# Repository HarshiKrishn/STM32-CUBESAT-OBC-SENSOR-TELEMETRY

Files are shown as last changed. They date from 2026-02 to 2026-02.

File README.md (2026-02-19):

# STM32 CubeSat OBC – Sensor Telemetry System

A custom-designed STM32-based On-Board Computer (OBC) for CubeSat applications with integrated sensor telemetry and power subsystem.

---

## 🚀 Overview

This project implements a CubeSat OBC built around STM32 microcontroller for:

- Sensor data acquisition
- Telemetry formatting
- Power subsystem integration
- Communication interface support

Designed completely in KiCad.

---

## 🧠 System Architecture

- MCU: STM32
- Power Regulation: 3.3V & 5V rails
- Communication:
  - UART
  - I2C
  - SPI
- Telemetry Output Support

---

## 🔌 Power Subsystem

- Battery input stage
- Voltage regulation
- Protection circuitry
- Filtering and decoupling

---

## 📡 Telemetry

- Sensor data acquisition
- Structured data formatting
- Ready for ground-station transmission

---

## 🖥️ Tools Used

- KiCad (Schematic + PCB)
- MATLAB (Validation)
- Proteus (Simulation)
- OnShape (Mechanical validation)

---

---

## 📂 Repository Structure

- `/Schematic`
- `/PCB`
- `/3D_Images`
- `/Docs`

---
## 3D PCB View

### Top View
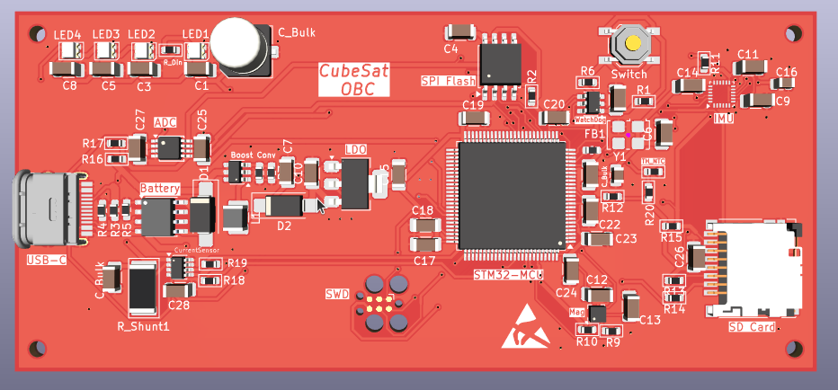
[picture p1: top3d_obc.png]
Top View


### Bottom View
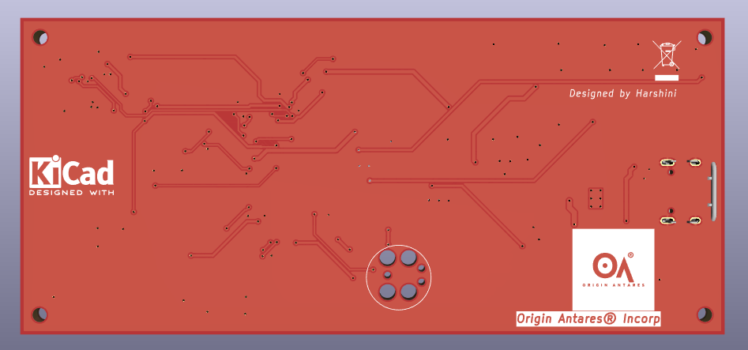
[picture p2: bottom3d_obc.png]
Bottom


## 👤 Author

Designed and developed by Harshini  
Embedded Systems & PCB Design Enthusiast

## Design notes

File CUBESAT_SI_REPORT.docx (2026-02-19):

# STACKUP

# FREQUENCY DOMAIN ANALYSIS

## FLASH MEMORY

DRIVER – STM32

RECIEVER – FLASH MEMORY

Signal | Parameter | Model
SPI_MISO, MOSI, SCK | Driver Model | STM32
| Receiver Model | FLASH MEMORY

FREQUENCY – 20MHz

PORTS(STM32) | Name of the Signal | PORTS(FLASH)
P1 | SPI1_flash_MISO | P2
P3 | SPI1_flash_MOSI | P4
P5 | SPI1_flash_SCK | P6

RL, p1, p1 ; p2,p2

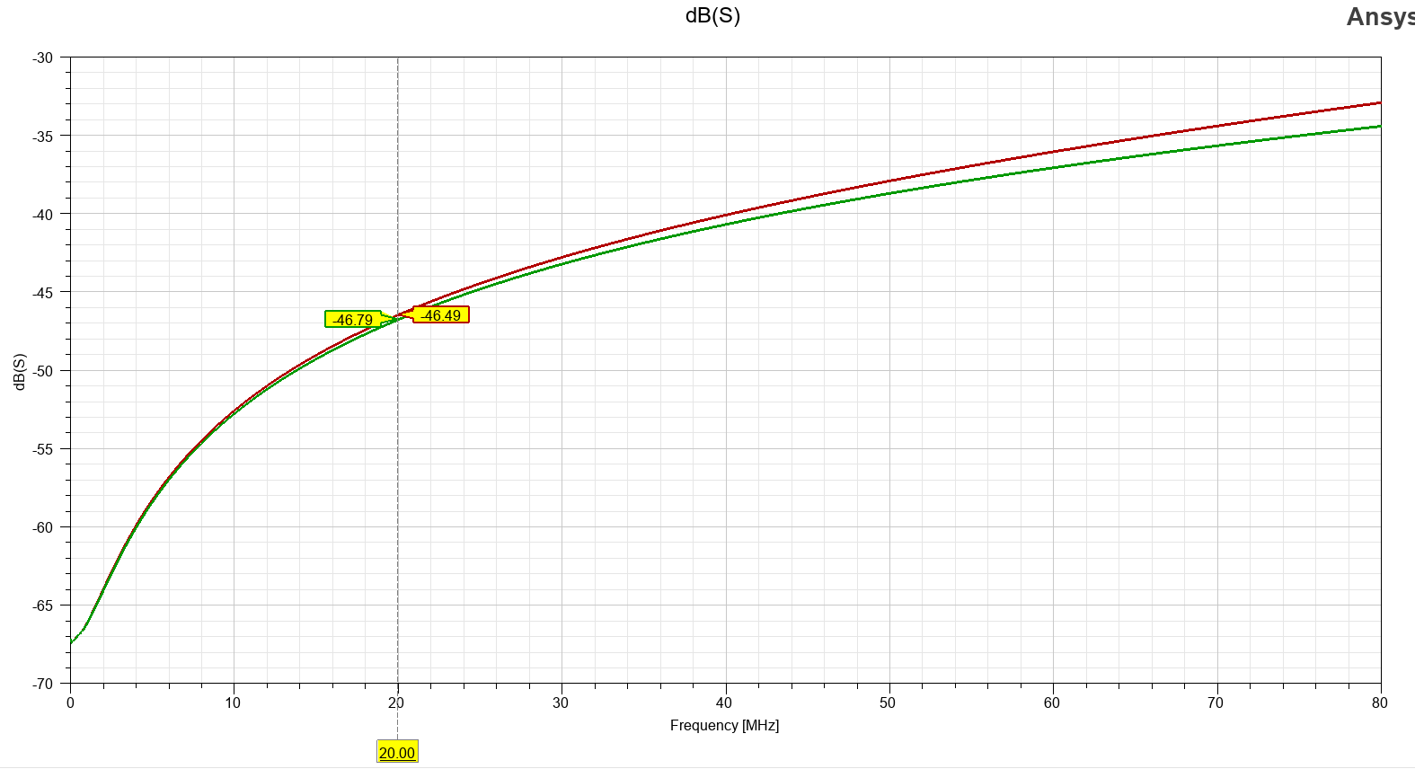
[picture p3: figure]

RL p3, p3 ; p4, p4

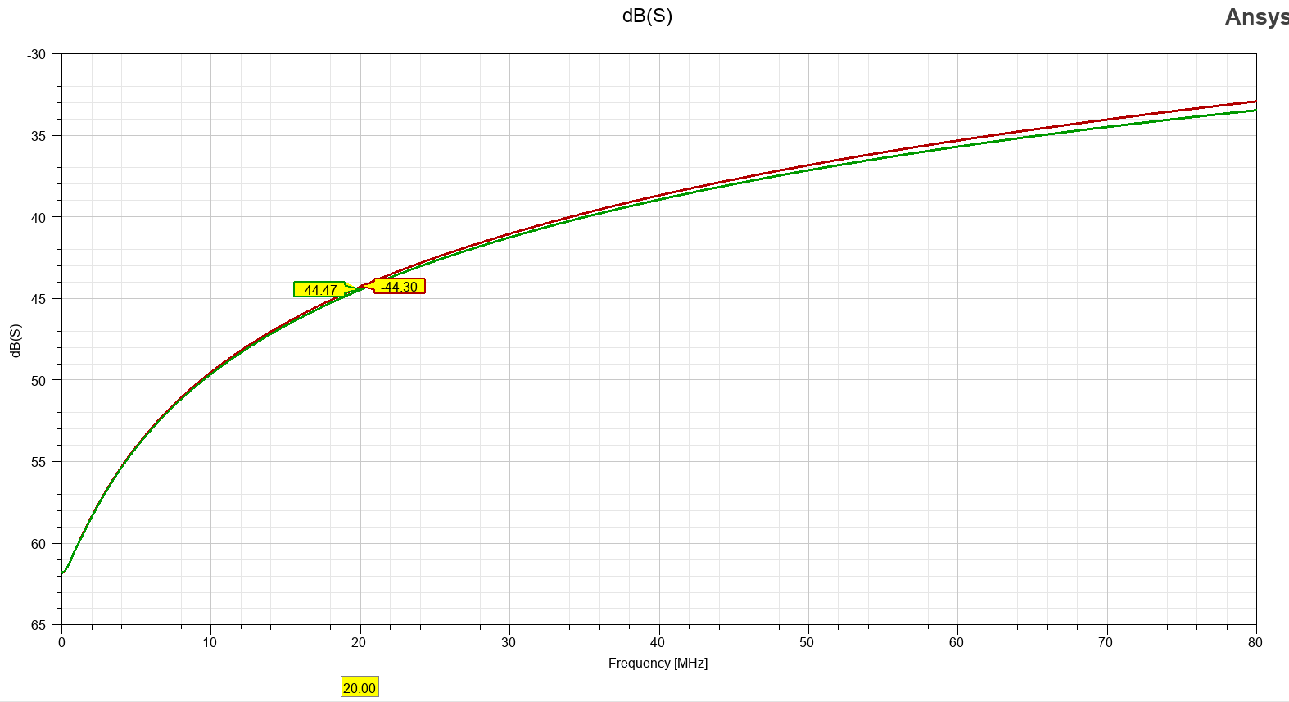
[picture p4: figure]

RL p5, p5; p6,p6

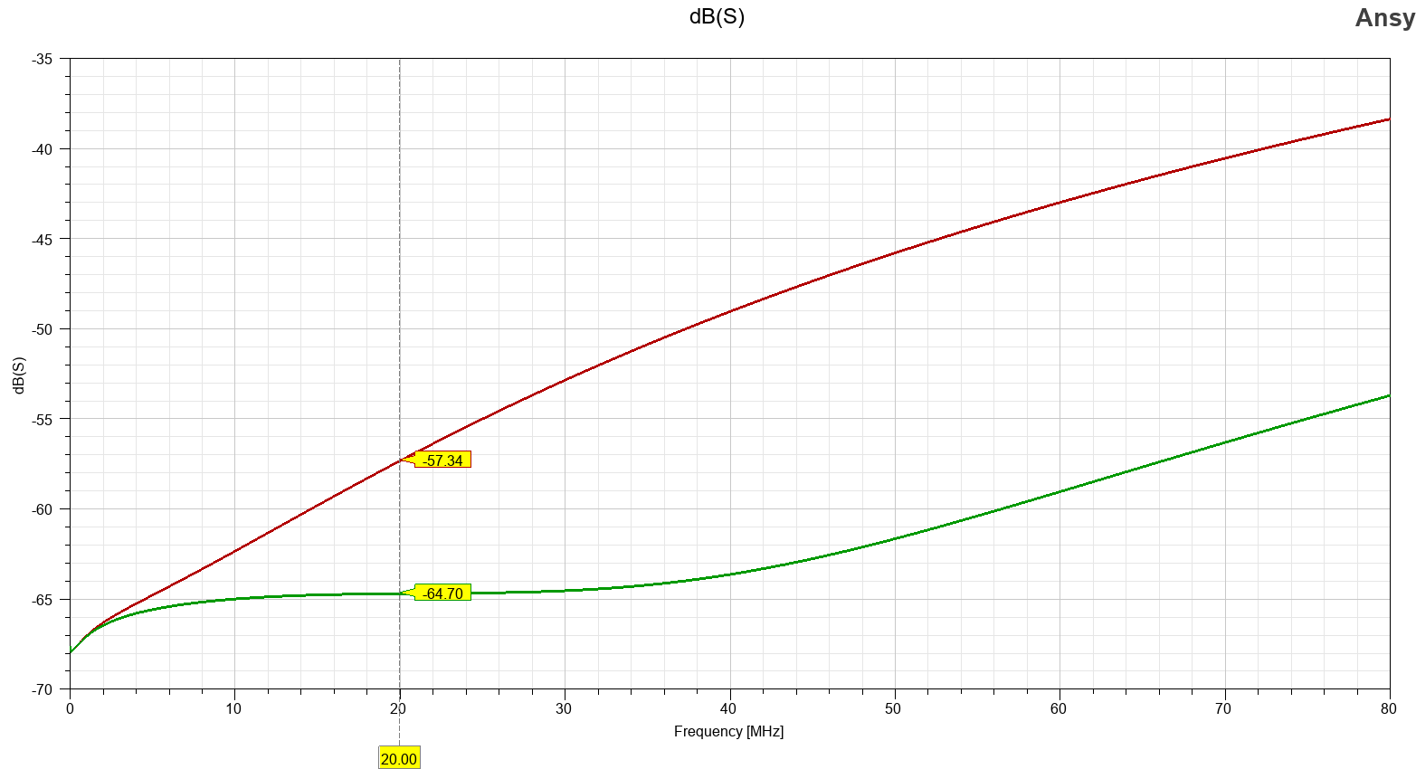
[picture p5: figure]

IL for p1,p2 ; p3, p4 ; p5, p6

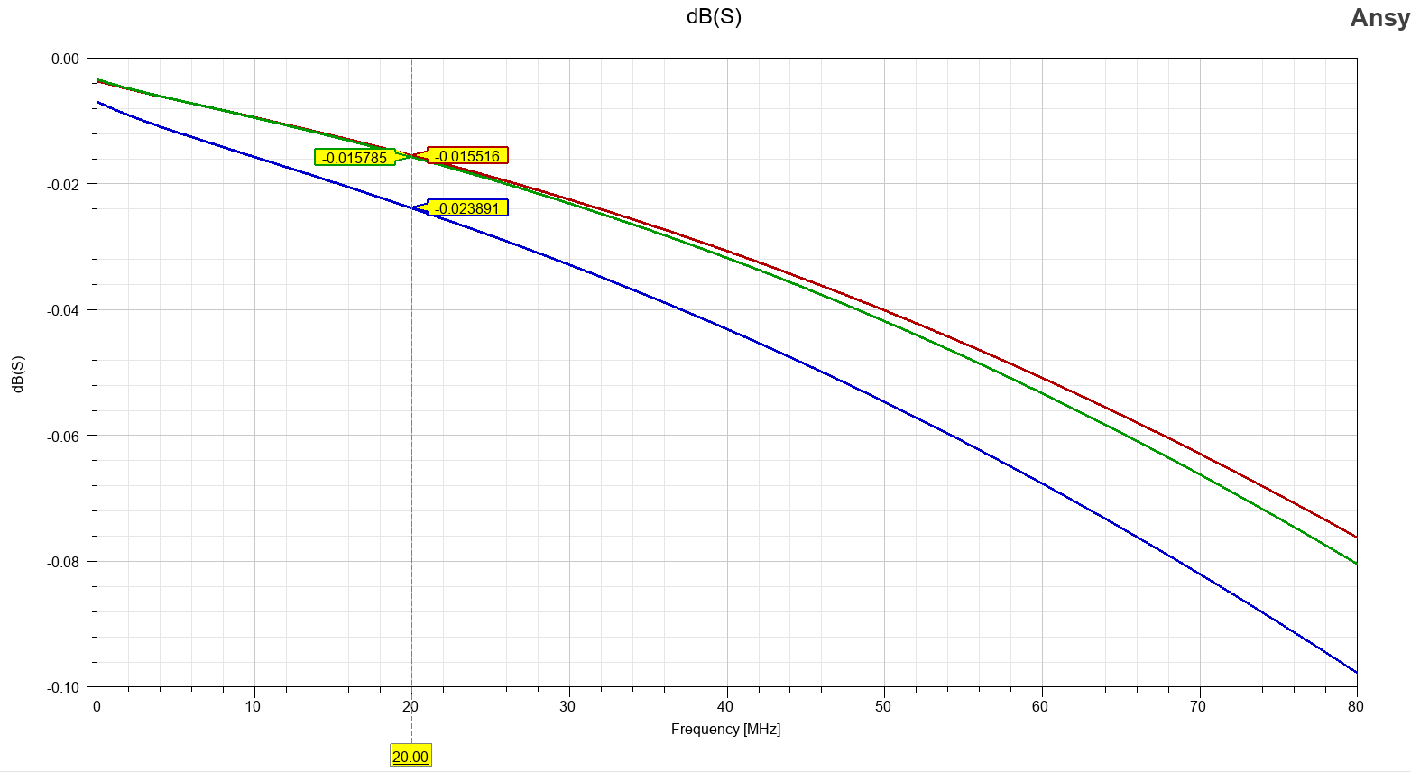
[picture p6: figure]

## SD CARD

DRIVER – STM32

RECIEVER – SD CARD

Signal | Parameter | Model
SPI_MISO, MOSI, SCK | Driver Model | STM32
| Receiver Model | SD CARD

FREQUENCY – 20MHz

Frequency domain analysis

PORTS(STM32) | Name of the Signal | PORTS(SD CARD)
P1 | SPI1_SDCARD_MISO | P2
P3 | SPI1_SDCARD_MOSI | P4
P5 | SPI1_SDCARD_SCK | P6

RL, p1, p1 ; p2, p2

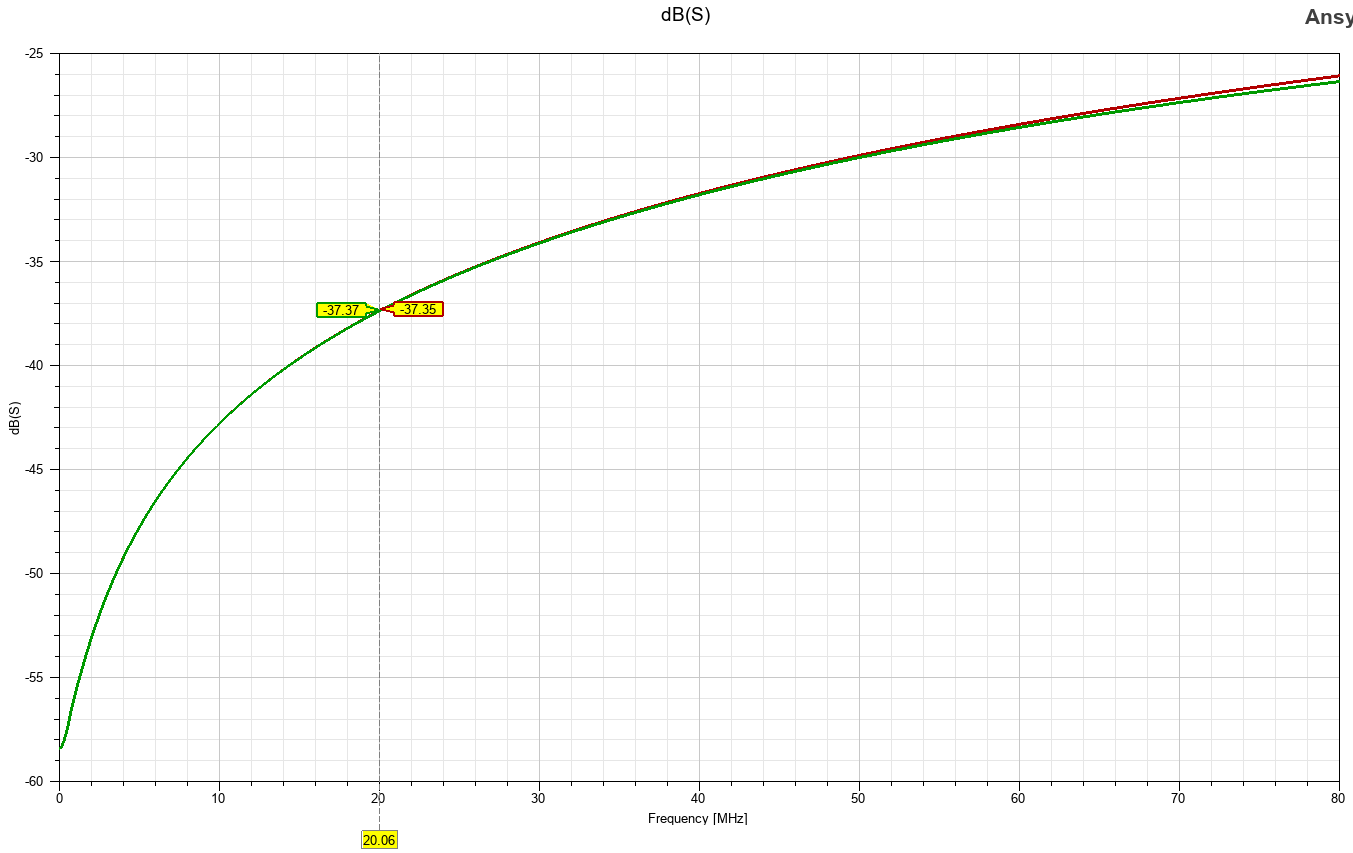
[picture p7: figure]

RL p3, p3 ; p4, p4

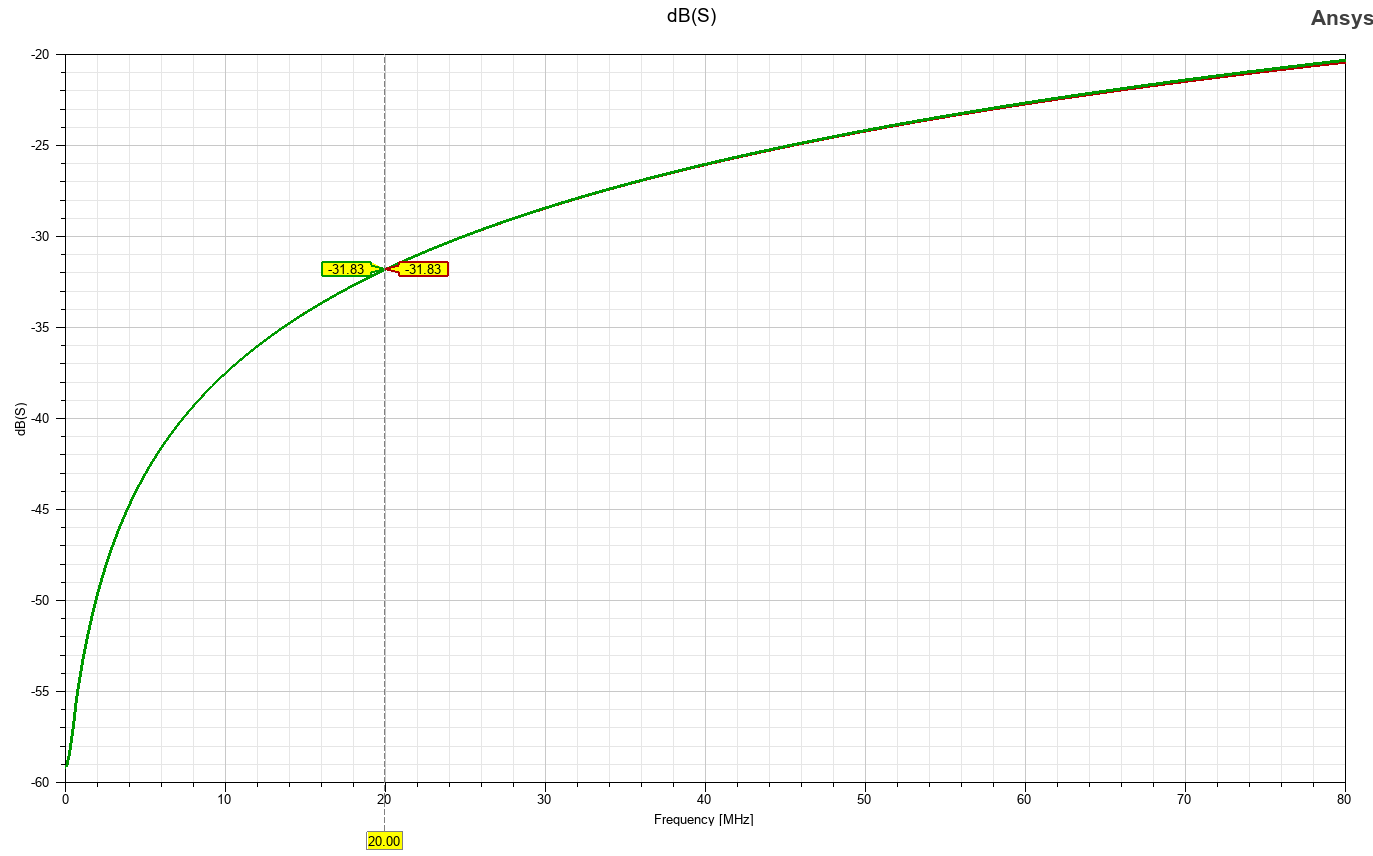
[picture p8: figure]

RL p5, p5; p6,p6

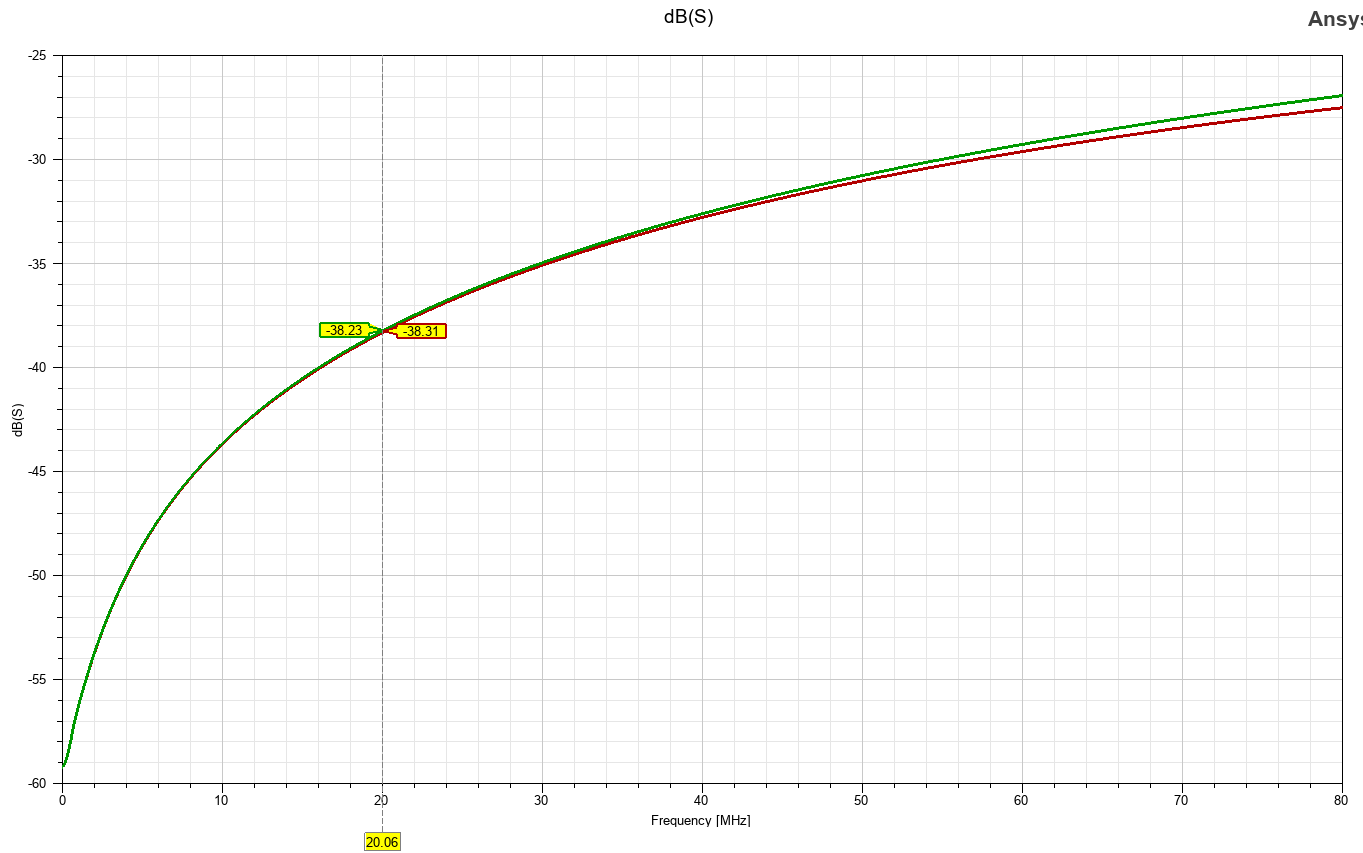
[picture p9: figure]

IL for p1,p2 ; p3, p4 ; p5, p6

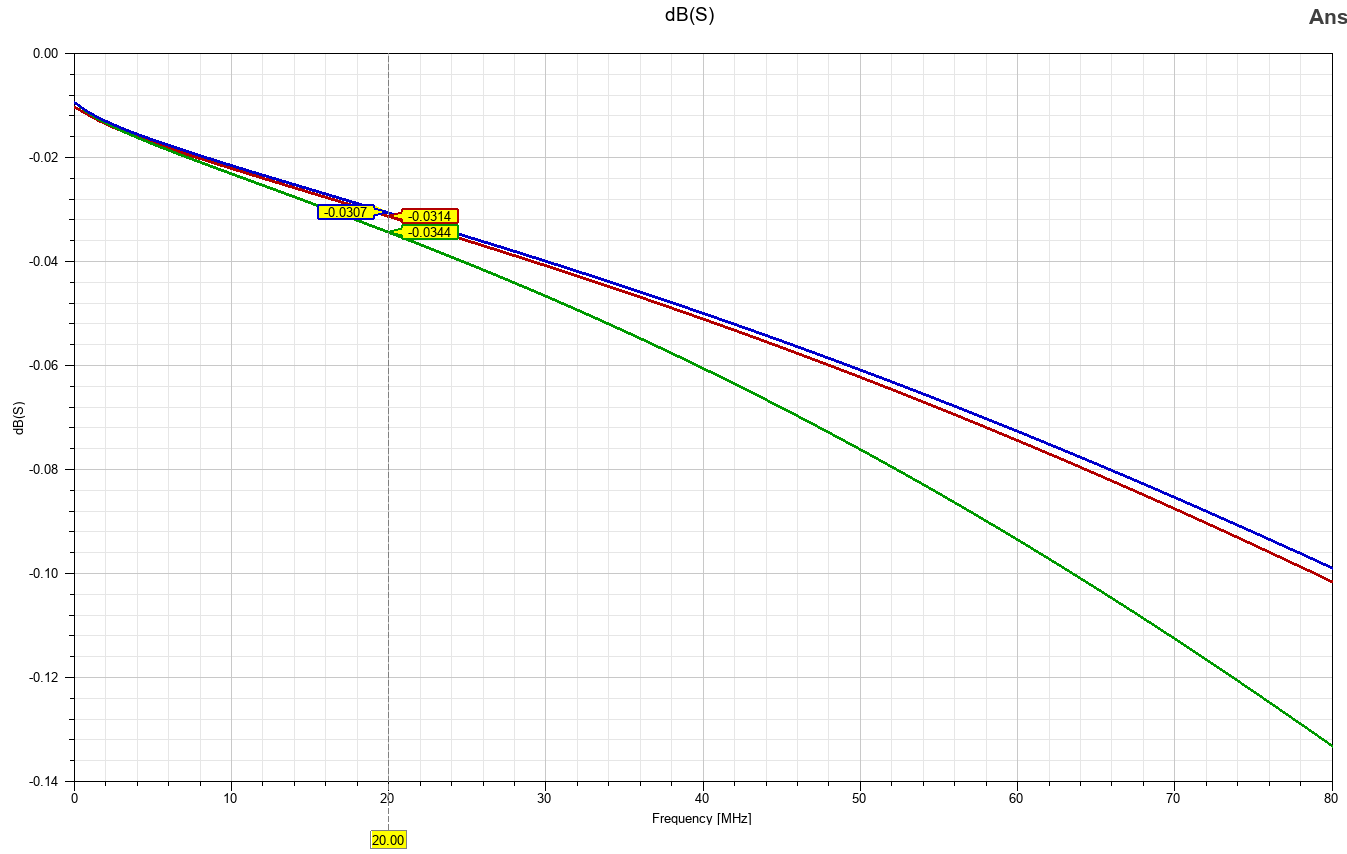
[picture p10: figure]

## IMU SENSOR

DRIVER – STM32

RECIEVER – IMU

Signal | Parameter | Model
SPI_MISO, MOSI, SCK | Driver Model | STM32
| Receiver Model | IMU SENSOR

FREQUENCY – 10MHz

Frequency domain analysis

PORTS(STM32) | Name of the Signal | PORTS(IMU)
P1 | SPI1_IMU_MISO | P2
P3 | SPI1_IMU_MOSI | P4
P5 | SPI1_IMU_SCK | P6

RL, p1, p1 ; p2, p2

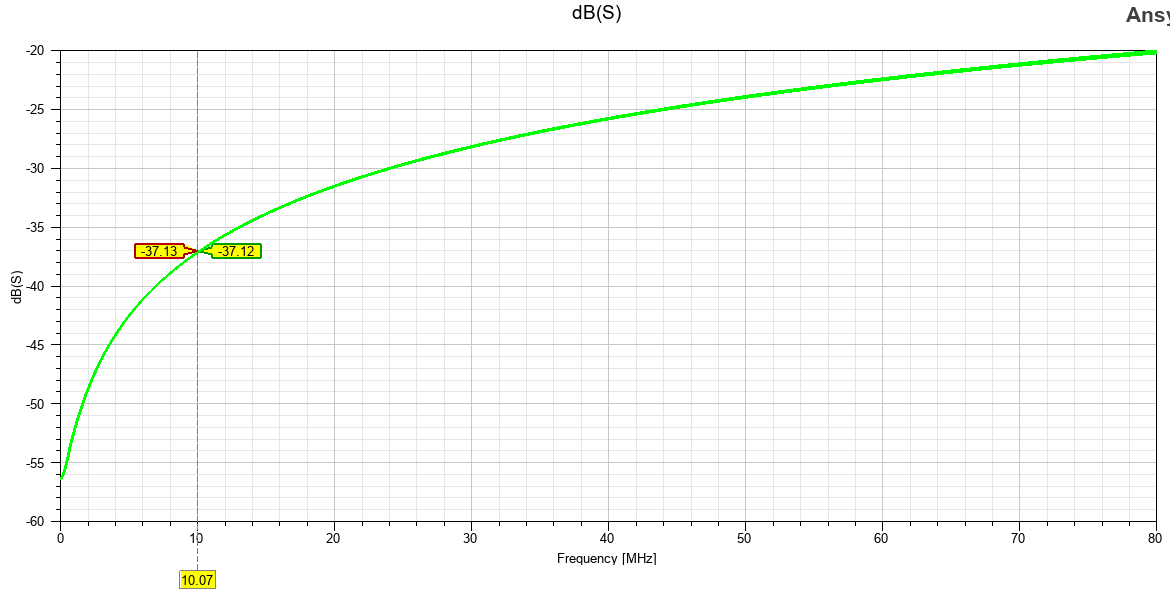
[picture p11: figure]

RL p3, p3; p4, p4

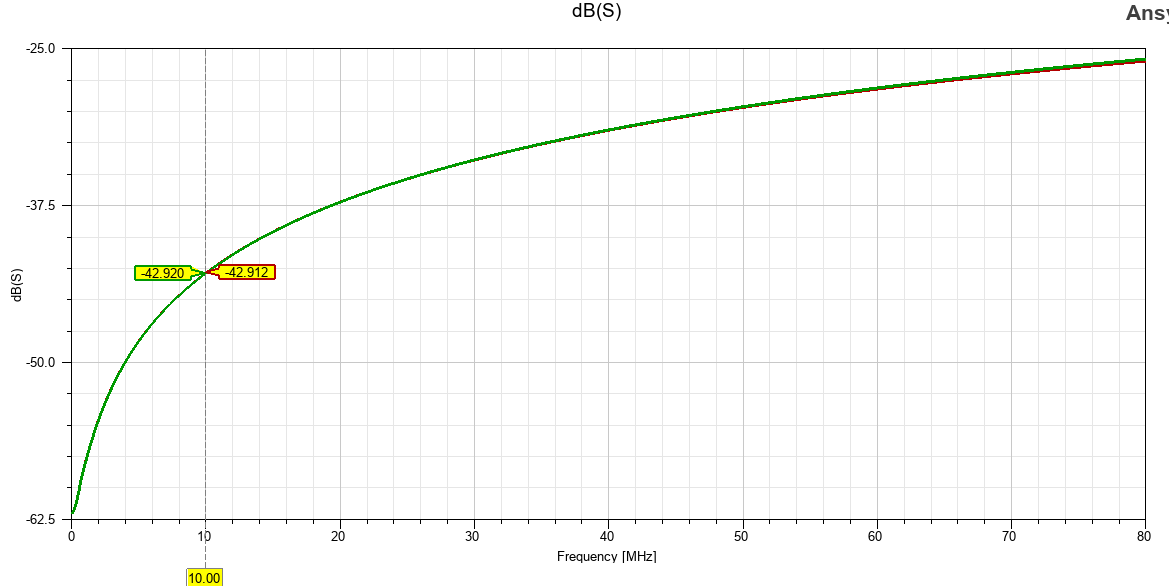
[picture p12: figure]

RL p5, p5; p6, p6

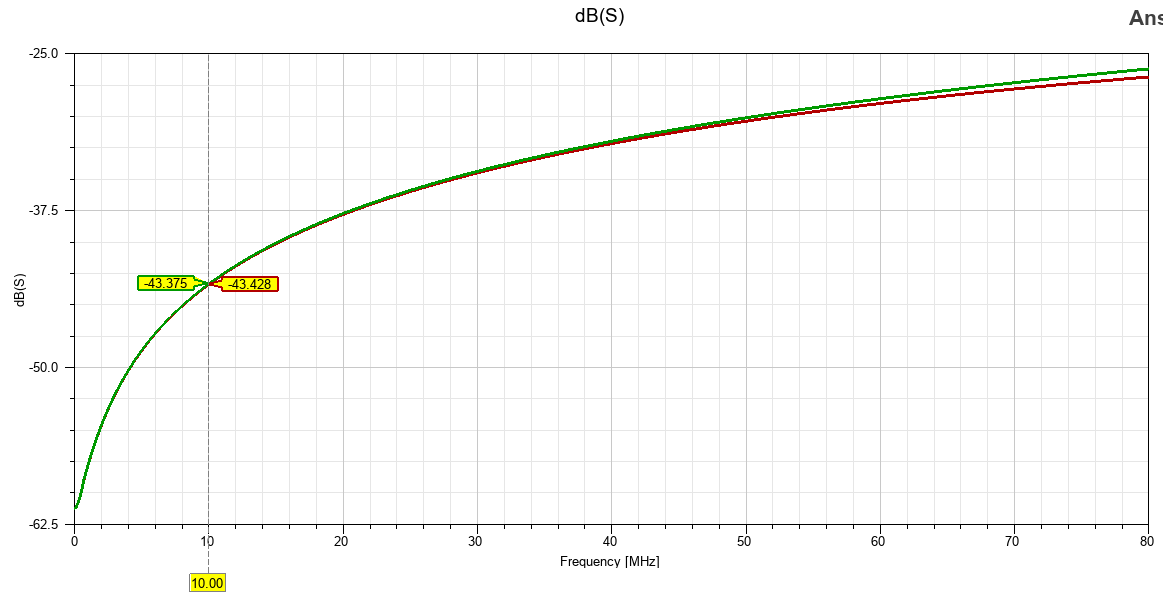
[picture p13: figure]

IL for p1, p2 ; p3, p4; p5, p6

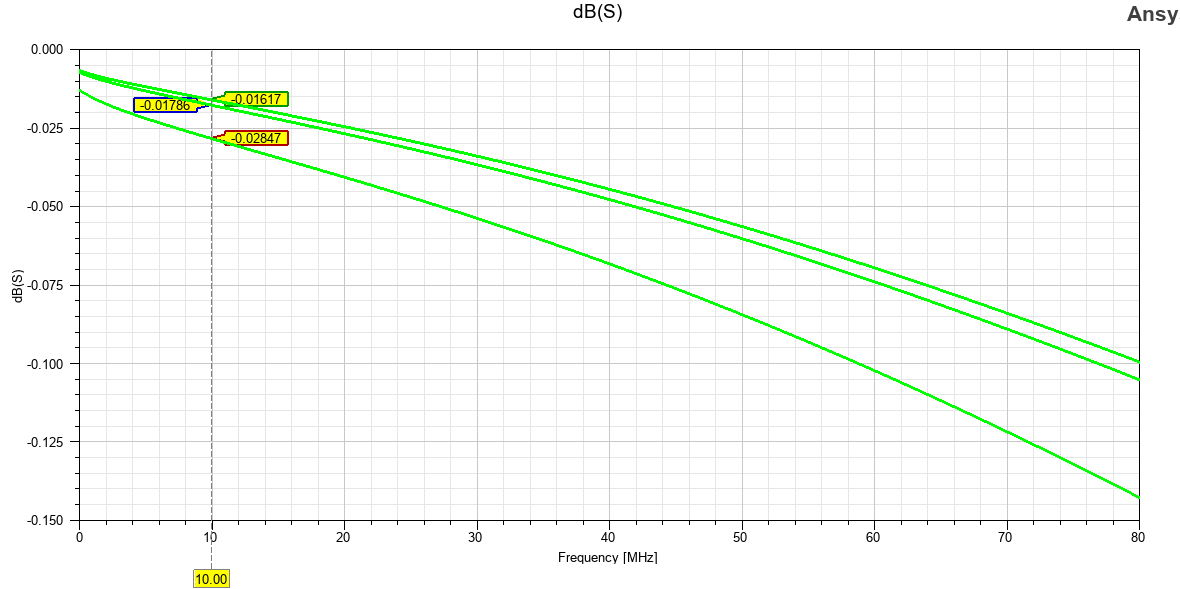
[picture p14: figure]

## I2C

DRIVER – STM32

RECIEVER – I2C

Signal | Parameter | Model
SPI_MISO, MOSI, SCK | Driver Model | STM32
| Receiver Model | CURRENT SENSOR

FREQUENCY – 10MHz

Frequency domain analysis

PORTS(STM32) | Name of the Signal | PORTS(CURRENT SENSOR)
P1 | SPI1_I2C_SCL_MISO | P2
P3 | SPI1_I2C_SDA_MOSI | P4

RL, p1, p1; p2, p2

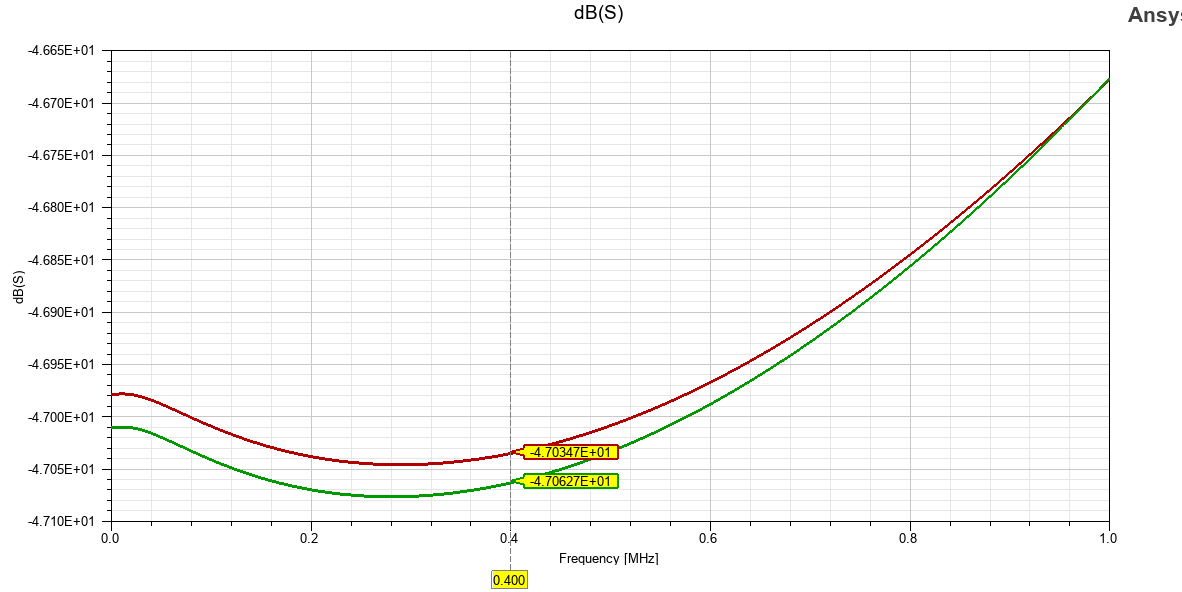
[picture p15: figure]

RL p3, p3; p4, p4

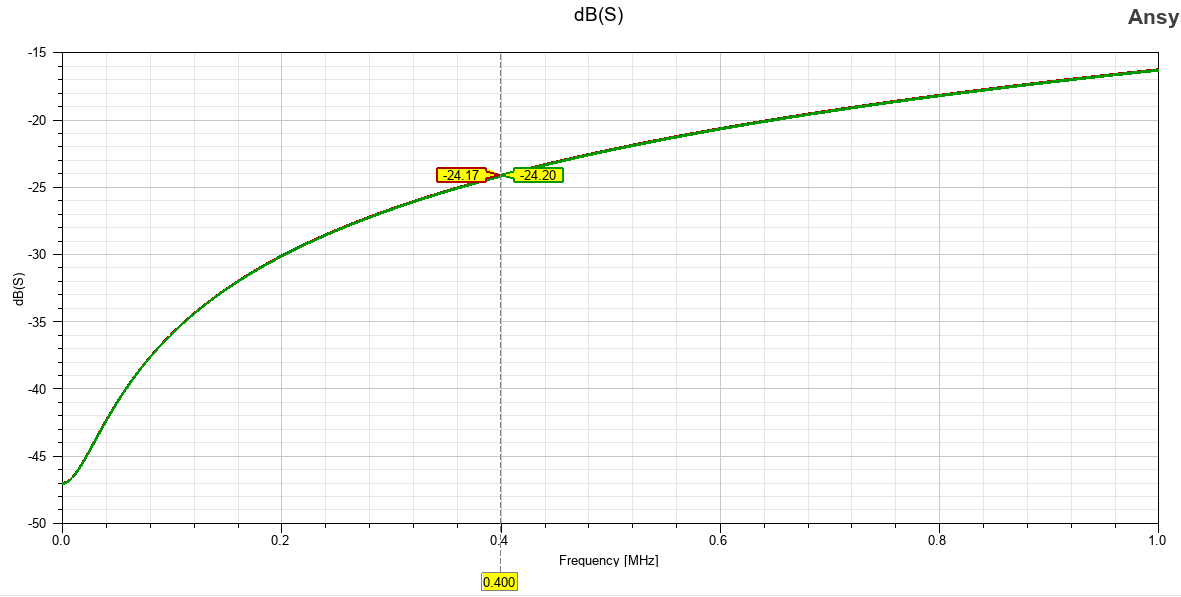
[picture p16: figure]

IL for p1, p2; p3, p4; p5, p6

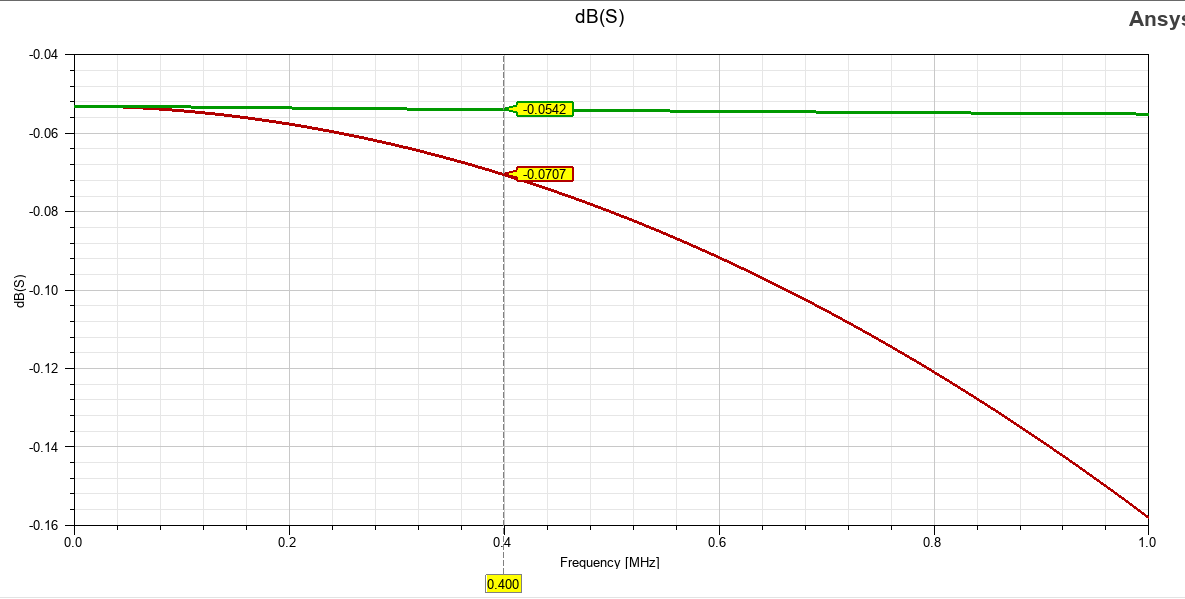
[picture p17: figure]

# TIMING DOMAIN ANALYSIS

## SDCARD

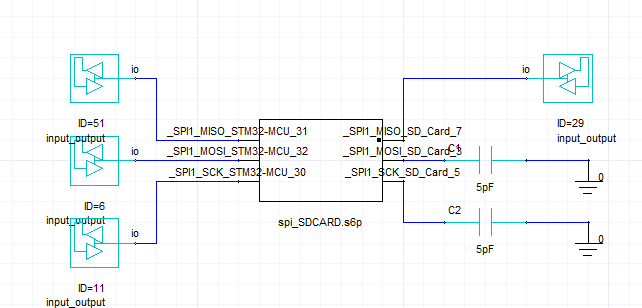
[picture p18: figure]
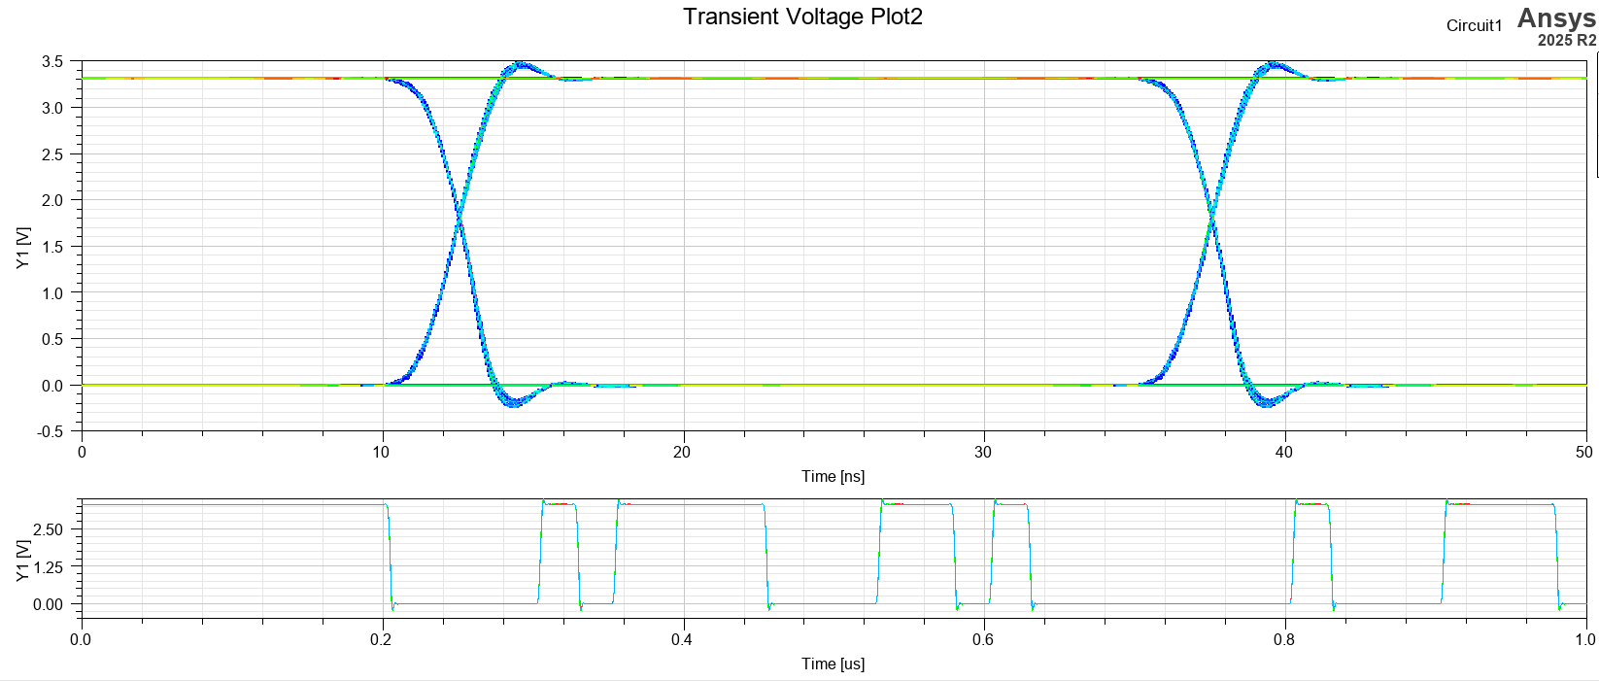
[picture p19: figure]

## FLASH MEMORY

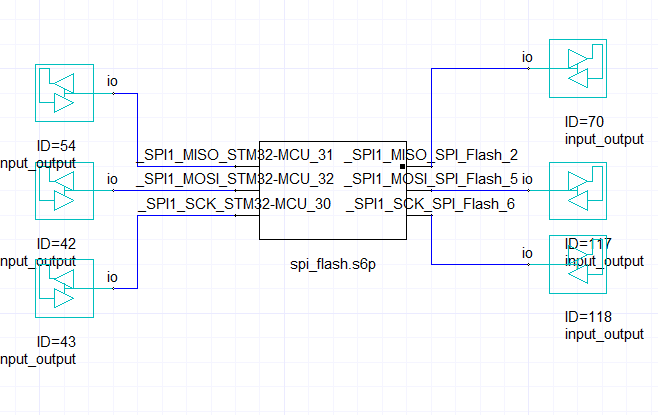
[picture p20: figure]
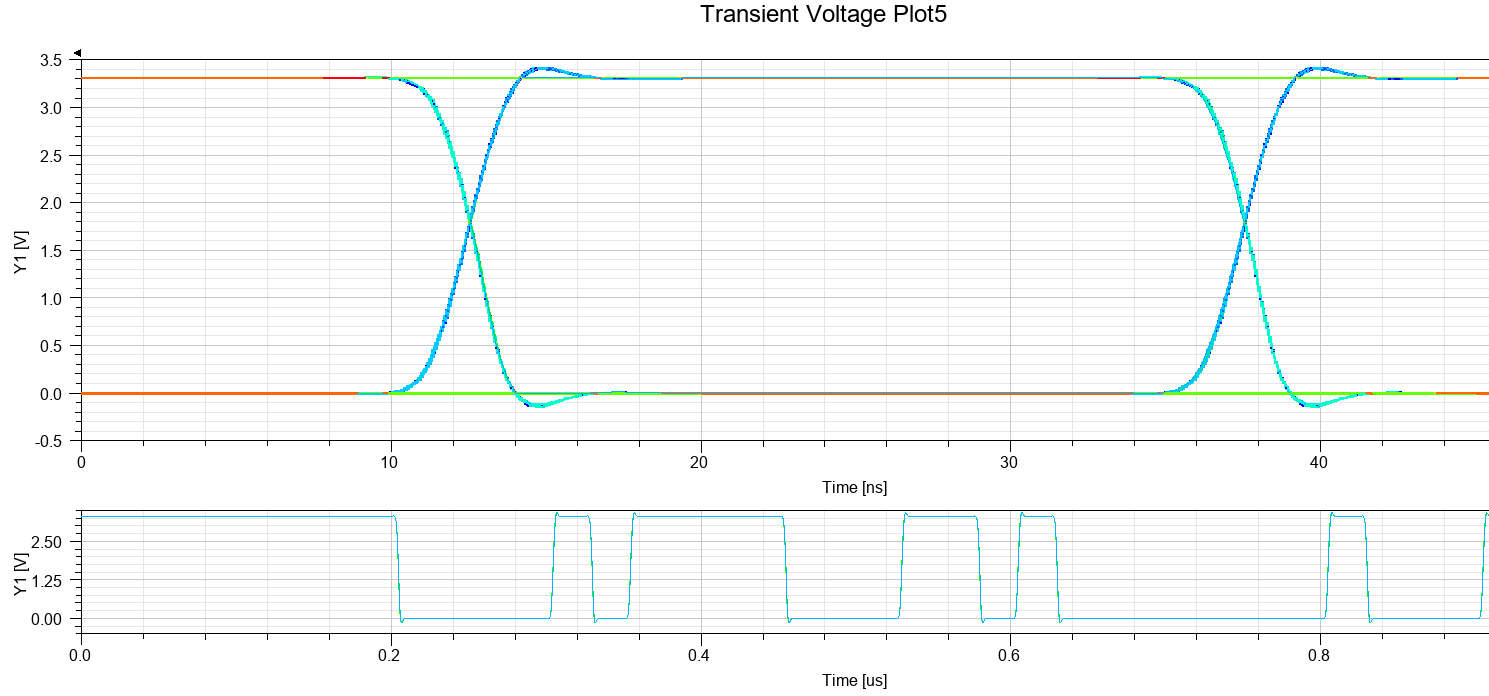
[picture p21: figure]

## IMU

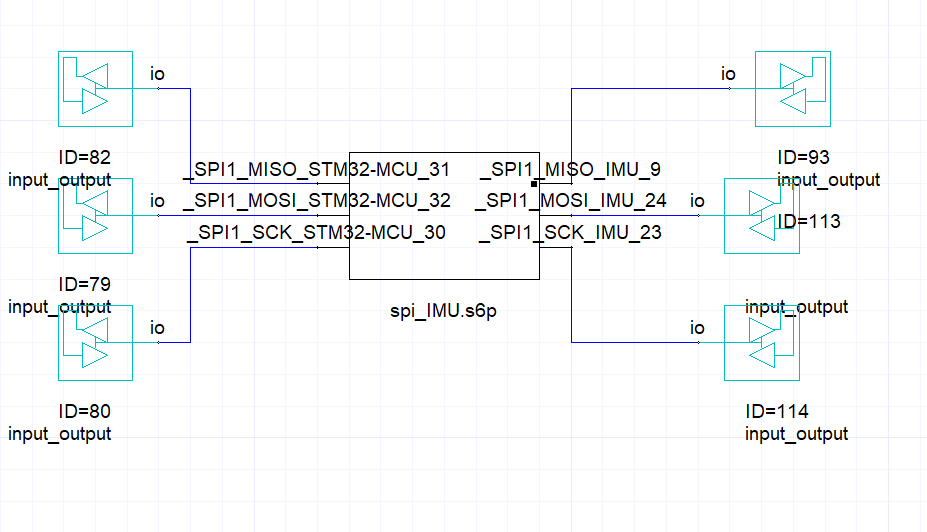
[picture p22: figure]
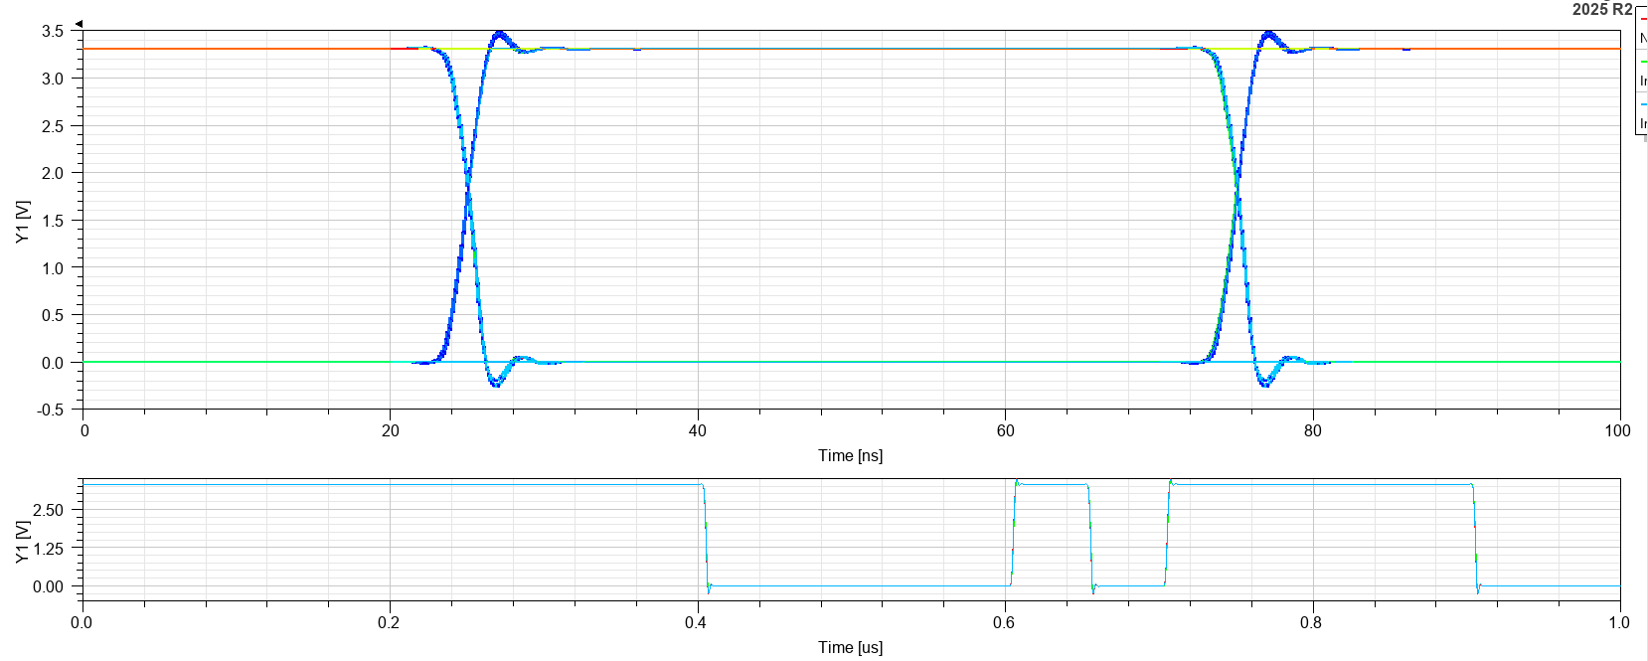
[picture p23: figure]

## I2C

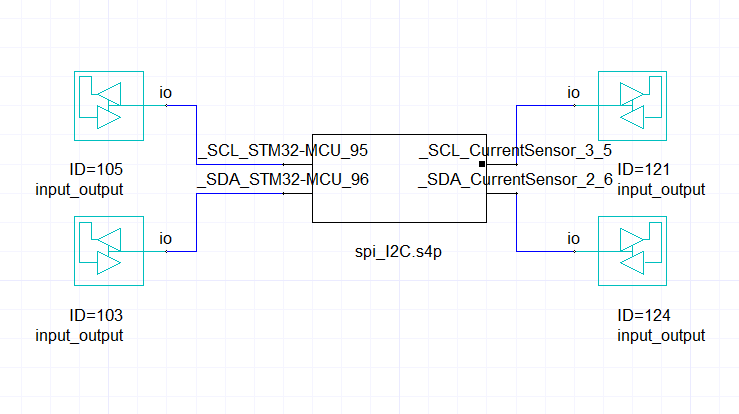
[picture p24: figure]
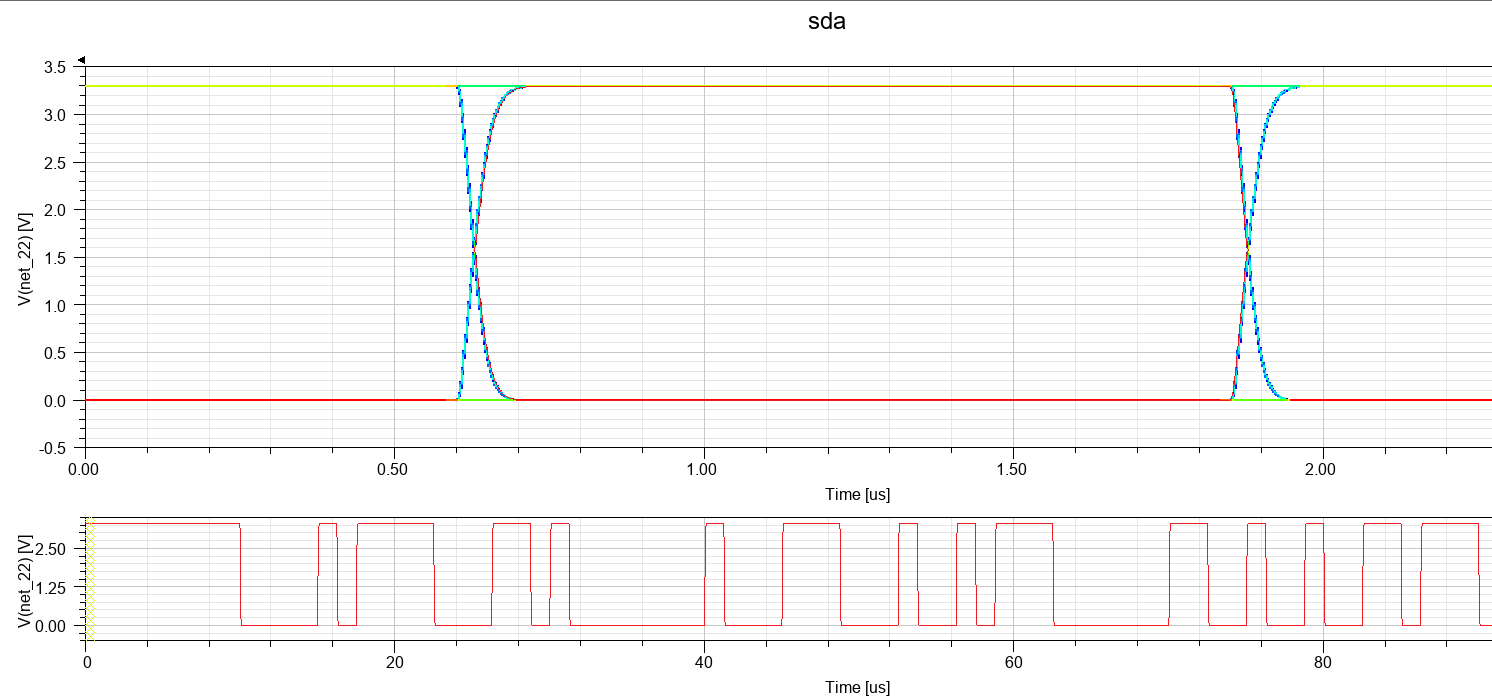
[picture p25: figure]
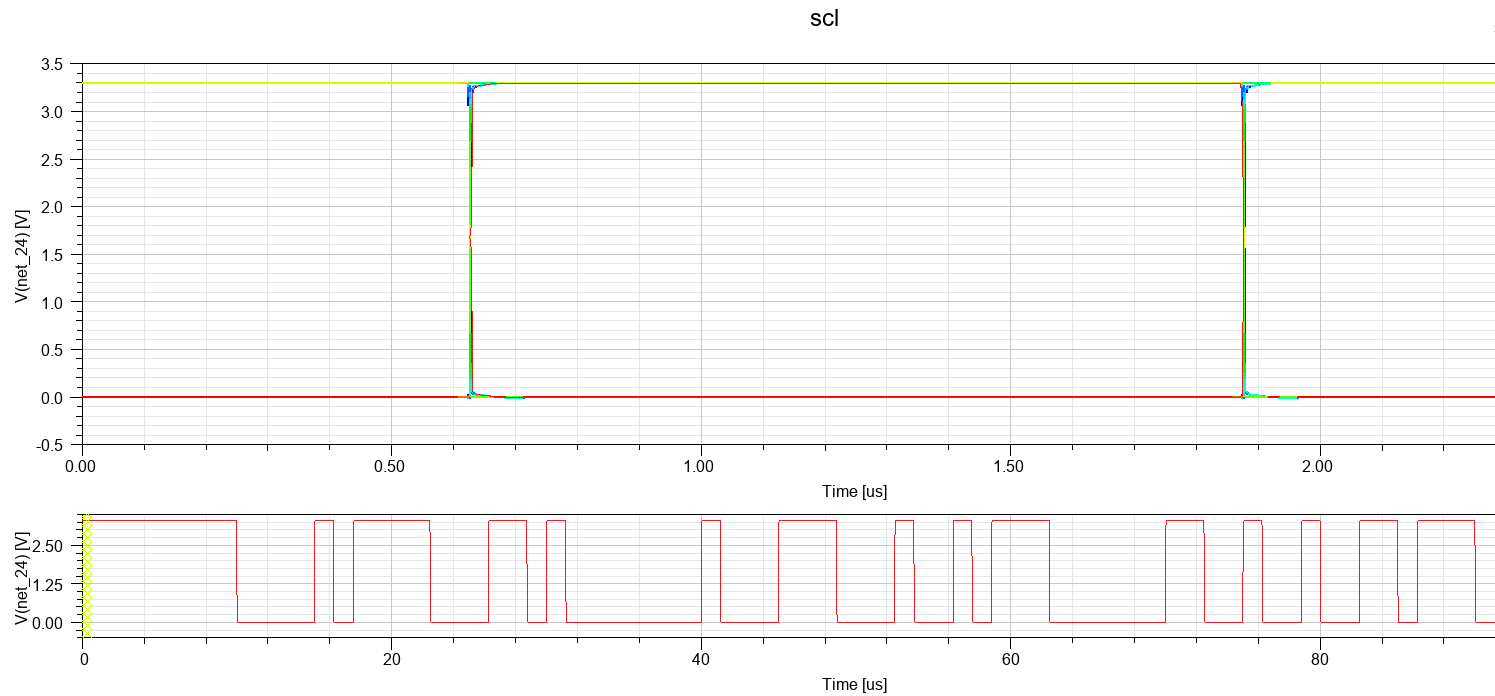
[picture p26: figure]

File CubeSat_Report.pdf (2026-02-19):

# Design and Development of STM32-Based CubeSat OBC

## ABSTRACT:

This project presents the design and dvelopment of a Cubesat-Level OBC prototype based on the STM32 MCU.
The objective of this work is to design a compact, reliable and power-efficient Embedded Hardware system capable of managing the Power Regultion , Sensor Telementry acquisition, data logging, and subsystem monitoring.
The complete system was designed using KiCad from Schematic to PCB Layout and 3D verification.
The design consists of a Li-ion battery charging stage using a TP4056 linear charger, followed by a Boost conv. For 5V rail generation and used an LDO regulatr for stable 3V3 logic supply.STM32 MCU serves as the central unit, interfacing , interfacing with peripheral devices including SPI Flash Memory, SD card storage, an Inertial Measurement Unit(IMU), Current Sensor, Thermistor-based temparature Monitoring, and an ADC-based battery Voltage measurement. A SWD interface is incoroporated for debugging and Frimware programming, while status LEDs provide visual system diagnostics.
The design Workflow followed a schematic apprach: requirement definition, block level schematic design, component selection based on datasheet analysis, footprint assignment, PCB planning, controlled routing, ground plane implementation, DRC verification.
The final result is a 2-layer PCB implementation demonstrating a structured power distribution strattegy, modular subsytem integration , and adherence to embedded hardware design best practices.

## SYSTEM ARCHITECTURE:

## Overall Architecture Overview-

The purposed CubeSat On-Board Computer (OBC) is designed as a modular embedded system integrating Power regulation, Data acquisition, Storage and Subsystem monitoring within a compact 2-layer PCB architecture. The system architecture is derived directly from the schematic design and is organised into functional blocks to ensure clarity,maintainability and electrical reliability.
The architecture is divided into the fllowing subsystems -
1. Power Input and Charging block
2. Battery and Energy Storage block
3. Voltage Regulation Block

4. Microcontroller Core block
5. Memory and Data storage block
6. Sensor Telemetry block
7. ADC & Voltage monitoring block
8. Debug & Programming Interface
9. Grounding and Power distribution network
I. Power Input and Charging block The power input stage is implemented using a USB-C interface configured for 5V default operation. This stage provides external power for battery charging and initial system startup.
The charging functionality is implemented using the TP4056 linear Li-ion battery charger. The TP4056 operates using a constant-current/constant-voltage(CC/CV) charging algorithm, terminating charge at ~4.2V . The exposed thermal pad is connected to ground with thermal vias to improve heat dissipation, as observed in the schematic and PCB layout.
This block ensures:
- Controlled charging current
- Thermal regultion
- Safe battery voltage limiting
- Stable transition between external power and battery operation
The Schematic flow shows a direct path from USB_5V to the TP4056 input, followed by the battery output connection to the system power rail.

II. Battery & Energy Stroage Block
The Li-ion battery serves as the primary energy storage elemnt. It supplies the system during standalone operation and acts as an energy buffer during load transients.
A bulk capacitor is placed across the battery rail to stabilize voltage flucuations . The battery output feeds the boost converter input stage, forming the next level of power conditioning.
Trace width considerations and placement strategy in the schematic ensure that high-current battery paths remain short and low impedance.

III. Voltage Regulation Block
The regulation stage consists of two sub-blocks:
- Boost Converter: A DC-DC boost converter is implemented to step-up the battery voltage (3-4.2V) to a regulated 5V rail. The boost topology includes
- Switching controller
- Inductor
- Schottky diode

- Input and output capacitors
Special layout emphasis was placed on minimizing the high-di/dt switching loop. The schematic arrangement ensures that the inductor,diode,and capacitors from a compact loop to reduce EMI and switching noise.
- LDO Regulator: The 5V output from the boost stage feeds a low-droupot regulator
(LDO) t generate a stable 3.3V rail for digital logic and sensors. The LDO ensures:
- Low ripple output
- Noise suppression
- Stable supply for MCU and peripherals
This dual-stage regulation(Boost+LDO) improves power integrity by siolating switching noise from sensitive digital circuits.


IV. Microcontroller Core block The central processing unit is an STM32 microcontroller selected for its:
- Sufficient GPIO availability
- Multiple SPI and I2C interfaces
- ADC capability
- Low-power operation
The MCU handles:
- Sensor data acquisition
- Memory management
- SPI and I2C communication
- ADC sampling


- Current monitoring
- SD card logging
- System diagnostics

An external watchdog circuit is integrated to enhance reliability by resetting the MCU in case of software malfunction.

V. Memory and Data Storage Block
The system integrates two storage mechanisms:
- SPI Flash Memory: Used for firmware backup and non-volatile storage. Connected via SPI interface to the MCU. Short trace routing and controlled layout minimize signal degradation.

- SD Card Interface: Used for high-capacity telemetry data logging. Connected using SPI mode for simplicity. The connector is positioned near the board edge for accessibility. Proper pull-ups and short routing maintain signal integrity.


VI.Sensor Telemetry Block
The telemetry subsystem integrates sensors for system monitoring and data acquisition:
- IMU (Inertial Measurement Unit) for motion sensing
- Thermistor for temperature measurement
- Current sensor with shunt resistor
- Battery voltage monitoring using resistor divider + ADC
Telemetry Data Flow:
Sensors → Analog/Digital Interface → STM32 MCU → Data Processing → Storage (SPI Flash / SD Card)
The MCU periodically samples telemetry data and stores or transmits it depending on mission logic.
- IMU (Inertial Measurement Unit):

Purpose
The IMU measures acceleration and angular motion of the satellite. In CubeSat systems, IMU data is used for:
- Attitude determination

- Motion tracking
- Stabilization algorithms
- Event detection

Interface
The IMU is connected to the STM32 via SPI (preferred for reliability and noise immunity). SPI was selected due to:
- Higher data throughput
- Better noise resistance compared to I2C
- Dedicated chip-select control

Design Considerations
- Short SPI traces between MCU and IMU
- Dedicated ground stitching around IMU
- Placement away from boost converter inductor
- Decoupling capacitor placed close to sensor supply pin
Magnetic interference from switching inductors can affect IMU readings; therefore, placement was optimized to isolate it from noisy power sections.


- Current Sensor Block

Purpose
The current sensor monitors system load current and provides telemetry for:
- Power budgeting
- Load profiling
- Fault detection
- Efficiency estimation

Implementation
The design uses:
- Low-value shunt resistor
- Current sensing IC (or amplifier)
- Kelvin routing for accurate measurement
The shunt resistor is placed in series with the battery or regulated output. The voltage drop across the shunt is amplified and fed to the MCU through an analog input or digital interface.

Layout Strategy
- High-current path kept short and wide
- Sense lines routed separately (Kelvin connection)
- Analog trace kept away from switching node
- Ground reference stable and low impedance
This ensures accurate current measurement without switching noise interference.


VII. Battery Voltage Monitoring (ADC Block)

Purpose
Battery voltage monitoring allows the MCU to:
- Estimate battery state of charge
- Detect undervoltage conditions
- Trigger safe shutdown
- Log battery health over time

Implementation
A resistive voltage divider is connected between battery positive terminal and ground. The midpoint of the divider feeds an ADC input of the STM32.
Since the battery voltage can reach 4.2V, the divider scales it down to a safe 0–3.3V range compatible with MCU ADC

Additional Considerations
- RC filtering added before ADC input
- Divider resistor values selected to minimize power loss
- Analog ground used as reference
The ADC sampling provides digital representation of battery voltage for firmware processing.


The thermistor forms part of a voltage divider circuit connected to the ADC for temperature estimation.

VIII. Debug and Programming Interface A Serial Wire Debug (SWD) interface is provided for:
- Firmware upload
- Real-time debugging
- System diagnostics
The SWD connector is placed at an accessible location on the PCB. Signal traces are short and directly routed to MCU debug pins.


Status LEDs are incorporated to indicate power presence, charging state, and MCU activity.

IX.Grounding and Power Distribution Strategy The architecture follows a 2-layer PCB configuration with:
- Bottom layer: Solid ground plane
- Bottom layer: Solid ground plane
Ground stitching vias are placed:
- Low impedance return path
- Reduced EMI
- Improved signal integrity
- Thermal distribution
X. ERC
Electrical Rule Check:

## PCB LAYOUT METHODOLOGY

## Overview -

The PCB layout of the CubeSat OBC was implemented using a structured and rule-driven approach to ensure electrical reliability, signal integrity, thermal stability, and manufacturability compliance. The design was implemented as a two-layer PCB, balancing performance and cost while maintaining a clean ground return path.
The layout methodology followed a systematic sequence:
I. Mechanical definition
II. Layer stack planning
III.Component placement strategy IV.Power routing
V. Signal routing
VI.Ground plane implementation VII.Design Rule Check (DRC) validation
VIII.3D verification
I. Mechanical Planning and Board Outline Before placement, the board outline was defined considering:
- Compact footprint
- Connector accessibility (USB-C, SD card)
- Mounting hole positioning
- Clearance from board edges (≥ 1 mm copper clearance)
All copper features were maintained at a minimum 1 mm distance from the board edge to prevent exposed copper during fabrication.

II. Layer stack planning
The PCB was implemented as a 2-layer board with the following configuration:
- Top Layer (F.Cu): Component placement and signal routing
- Bottom Layer (B.Cu): Continuous ground plane
The bottom layer was primarily reserved for ground to:
- Provide a low-impedance return path
- Reduce EMI
- Improve signal integrity

- Enhance thermal spreading
This configuration ensures stable reference for digital and analog signals.

III. Component placement strategy Component placement followed a functional zoning approach.

### 1. Power Section Placement

The power section (USB input, TP4056 charger, boost converter, LDO) was placed on one side of the board to isolate switching noise from digital and sensor sections.
Key principles followed:
- Inductor placed immediately next to SW pin
- Input and output capacitors placed as close as possible to regulator pins
- Short high-current loops
- Minimal switching node copper area
This reduces switching loop area and EMI radiation.

### 2. MCU Placement

The STM32 microcontroller was placed near the center of the board to minimize trace length to:
- SPI Flash
- SD card
- IMU
- ADC monitoring circuits
Decoupling capacitors were placed within 2–3 mm of each VDD pin to ensure stable supply filtering.

### 3. Sensor and Analog Placement

Sensitive analog components (thermistor, ADC divider, current sensing circuitry) were placed:
- Away from switching regulator
- In a relatively quiet ground region
- With short signal routing
The IMU was positioned away from the boost inductor to prevent magnetic interference.

### 4. Memory and Storage Placement

SPI Flash was placed close to the MCU to maintain short SPI trace lengths.
The SD card connector was positioned at the board edge for user accessibility and mechanical stability.

IV. Routing Strategy
Routing followed a strict priority-based order:

### 1. Step 1: High-Current Power Routing

- Battery traces routed first
- Boost converter high-current path routed with wide traces
- 3.3V main rail routed with sufficient width
Trace width was selected based on expected current.

### 2. Step 2: Switching Loop Optimization

For the boost converter:
- Minimized loop area between switch, inductor, diode, and capacitor
- Kept feedback trace short and isolated
- Avoided routing signals under the switching node
This is critical for reducing EMI and ripple.

### 3. Step 3: MCU Power Routing

- Routed VDD traces short
- Connected each decoupling capacitor directly to ground plane via short via
- Avoided shared return paths with switching current

### 4. Step 4: Digital Signal Routing

SPI and communication lines were routed:
- As short as possible
- Avoiding sharp 90° bends
- With consistent spacing
- Without crossing split ground areas
Where necessary, vias were used to escape tight pin spacing.

### 5. Step 5: Analog Routing

Analog signals (ADC inputs, current sense signals) were routed:
- Away from switching nodes
- With minimal crossing of digital traces
- With RC filtering where required
Kelvin routing principles were applied for current sense lines.

V. Ground Plane Implementation The bottom layer was filled with a continuous GND copper zone. Key grounding techniques:
- Solid ground reference under MCU
- Thermal vias under exposed pads
- Stitching vias around switching regulator
- Stitching vias near decoupling capacitors
- Perimeter stitching along board edges Ground stitching improves:
- Return current continuity
- EMI suppression
- Thermal dissipation
Care was taken not to split the ground plane with unnecessary signal routing.

VI.Thermal Management
Thermal vias were added under:
- TP4056 exposed pad
- High-power regulator components
This improves heat transfer from top copper to bottom ground plane. Component spacing was also considered to allow heat spreading.

VII. Design Rule Verification Design Rule Checks (DRC) were performed iteratively to ensure manufacturability. Key constraints enforced:
- Minimum clearance: 0.15–0.2 mm
- Minimum via drill: 0.3 mm
- Minimum annular ring: 0.15 mm
- Minimum hole clearance: 0.25 mm
Several DRC violations were encountered during layout, including:
- Thermal spoke clearance issues
- Annular width violations
- Via diameter mismatches
- Hole clearance violations


These were resolved through rule tuning and footprint adjustments, ensuring fabrication compatibility.

VIII. 3D Verification
The 3D viewer was used to:
- Verify connector orientation
- Confirm SD card alignment
- Check component spacing
- Validate mechanical clearances
Solder mask color and 3D rendering were also used for presentation verification.


IX.Manufacturability Considerations The layout was finalized only after:
- Eliminating all DRC errors
- Ensuring adequate copper-edge clearance
- Verifying drill sizes within fabrication limits
- Confirming proper silkscreen placement
The final design is compatible with standard PCB fabrication processes using 2-layer FR4 material.

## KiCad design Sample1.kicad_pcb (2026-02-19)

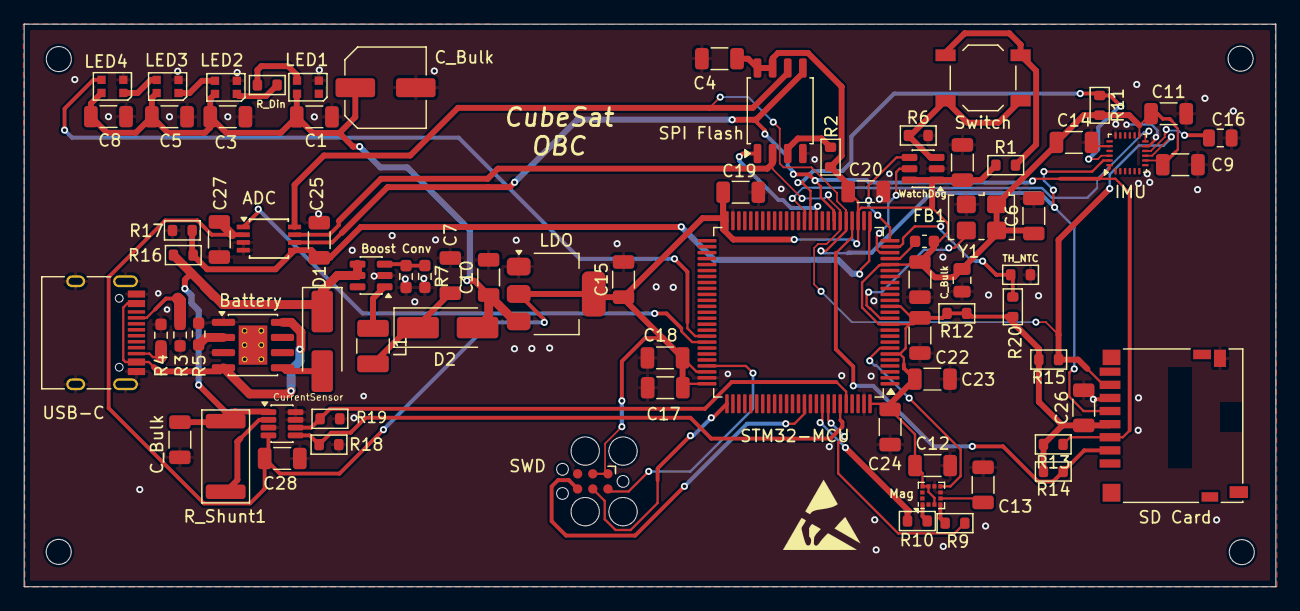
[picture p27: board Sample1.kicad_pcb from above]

Board: 2 copper layers, 105.0 x 47.2 mm, 77 parts (0 on the bottom side), 47 nets.

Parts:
ADC: ADC082S021; TSSOP-8_3x3mm_P0.65mm
Battery: TP4056-42-ESOP8; SOIC-8-1EP_3.9x4.9mm_P1.27mm_EP2.41x3.3mm_ThermalVias
Boost Conv: MT3608; SOT-23-6
C1, C2, C3, C5, C6, C8, C11, C12, C13, C14, C17, C18, C19, C20, C21, C22, C23, C25, C27, C28: 100nF; C_1206_3216Metric
C4, C9, C26: 1uF; C_1206_3216Metric
C7: 22µF; C_1206_3216Metric
C10, C15, C24: 10uF; C_1206_3216Metric
C16: 2.2uF; C_0805_2012Metric
C_Bulk: 100uF; C_1206_3216Metric
C_Bulk#2: 100uF; C_Elec_6.3x5.4
C_Bulk#3: 100uF; C_0805_2012Metric
CurrentSensor: INA219BxDCN; SOT-23-8
D1, D2: SS14; D_SMA_Handsoldering
FB1: Ferrite_Bead; Fuse_0603_1608Metric
IMU: ICM-20948; InvenSense_QFN-24_3x3mm_P0.4mm
L1: 10µH; L_1210_3225Metric_Pad1.42x2.65mm_HandSolder
LDO: AMS1117-3.3; SOT-223-3_TabPin2
LED1, LED2, LED3, LED4: WS2812B-2020; LED_WS2812B-2020_PLCC4_2.0x2.0mm
Mag: LIS2MDL; LGA-12_2x2mm_P0.5mm
R1, R11, R13, R14, R15, R20: 10k; R_0603_1608Metric
R2: 0; R_0603_1608Metric
R3, R4: 5.1k; R_0603_1608Metric_Pad0.98x0.95mm_HandSolder
R5: 2.4k; R_0603_1608Metric_Pad0.98x0.95mm_HandSolder
R6: 8.85k; R_0603_1608Metric
R7: 75k; R_0603_1608Metric_Pad0.98x0.95mm_HandSolder
R8: 10k; R_0603_1608Metric_Pad0.98x0.95mm_HandSolder
R9, R10, R18, R19: 4.7K; R_0603_1608Metric
R12: 10K; R_0603_1608Metric
R16: 100K; R_0603_1608Metric
R17: 33K; R_0603_1608Metric
R_Din: 330; R_0603_1608Metric
R_Shunt1: 0.1; R_2512_6332Metric
SD Card: Micro_SD_Card; microSD_HC_Hirose_DM3D-SF
SPI Flash: W25Q16JVSS; SOIC-8_5.3x5.3mm_P1.27mm
STM32-MCU: STM32L496VGTx; LQFP-100_14x14mm_P0.5mm
SWD: Conn_ARM_SWD_TagConnect_TC2030; Tag-Connect_TC2030-IDC-FP_2x03_P1.27mm_Vertical
Switch: SW_Push; SW_SPST_TL3342
TH_NTC: 10K@25degreeC; R_0603_1608Metric
USB-C: USB_C_Receptacle_PowerOnly_24P; USB_C_Receptacle_HRO_TYPE-C-31-M-12
WatchDog: TPL5010; SOT-23-6
Y1: SG-5032CAN; Oscillator_SMD_SeikoEpson_SG8002LB-4Pin_5.0x3.2mm

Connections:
/3V3: ADC.2 (V_{A}), C2.1, C4.1, C6.1, C9.1, C11.1, C12.1, C14.1, C15.1, C17.1, C18.1, C19.1, C20.1, C21.1, C22.1, C23.1, C24.1, C26.1, C27.1, C28.1, C_Bulk#3.1, CurrentSensor.4 (VS), FB1.2, IMU.8 (VDDIO), IMU.13 (VDD), LDO.2 (VO), Mag.3 (~CS), Mag.9 (Vdd), Mag.10 (Vdd_IO), R1.1, R2.1, R11.2, R12.1, R12.2, R13.2, R14.2, R15.2, R20.1, SD Card.4 (VDD), SPI Flash.7 (~HOLD/~RESET/IO_{3}), SPI Flash.8 (VCC), STM32-MCU.6 (VBAT), STM32-MCU.11 (VDD), STM32-MCU.14 (NRST), STM32-MCU.21 (VREF+), STM32-MCU.28 (VDD), STM32-MCU.50 (VDD), STM32-MCU.73 (VDDUSB), STM32-MCU.75 (VDD), STM32-MCU.100 (VDD), SWD.1 (VCC), SWD.3 (~RESET), WatchDog.1 (VDD), WatchDog.6 (~RST), Y1.1 (~ST), Y1.4 (VCC)
/5V: C1.1, C3.1, C5.1, C8.1, C10.1, C_Bulk#2.1, D2.2 (A), LDO.3 (VI), LED1.4 (VDD), LED2.4 (VDD), LED3.4 (VDD), LED4.4 (VDD)
/ADC_CS: ADC.1 (~CS), STM32-MCU.68 (PA9)
/Debug LEDs: LED4.3 (DIN), STM32-MCU.67 (PA8)
/EPS_O/P: Boost Conv.4 (EN), Boost Conv.5 (IN), C_Bulk.1, CurrentSensor.1 (IN+), D1.1 (K), R16.2, R_Shunt1.2
/EPS_V_ADC: ADC.5 (IN1), C25.1, R16.1, R17.1, STM32-MCU.26 (PA3)
/EXTI: Mag.7 (DRDY), STM32-MCU.7 (PC13)
/Flash_CS: SPI Flash.1 (~CS), STM32-MCU.35 (PB0)
/HSE_IN: STM32-MCU.12 (PH0), Y1.3 (OUT)
/I2C_SCL: R10.1, STM32-MCU.92 (PB6)
/I2C_SDA: R9.2, STM32-MCU.93 (PB7)
/IMU_CS: IMU.22 (~CS), R11.1, STM32-MCU.36 (PB1)
/IMU_INT: IMU.12 (INT1), STM32-MCU.37 (PB2)
/MCU_DONE: STM32-MCU.25 (PA2), WatchDog.4 (DONE)
/MCU_WAKE: STM32-MCU.23 (PA0), WatchDog.5 (WAKE)
/SCL: CurrentSensor.5 (SCL), R18.1, STM32-MCU.95 (PB8)
/SDA: CurrentSensor.6 (SDA), R19.2, STM32-MCU.96 (PB9)
/SD_CS: R14.1, SD Card.2 (DAT3/CD), STM32-MCU.29 (PA4)
/SPI1_MISO: ADC.7 (DOUT), IMU.9 (SDO/AD0), R15.1, SD Card.7 (DAT0), SPI Flash.2 (DO/IO_{1}), STM32-MCU.31 (PA6)
/SPI1_MOSI: ADC.6 (DIN), IMU.24 (SDA/SDI), R13.1, SD Card.3 (CMD), SPI Flash.5 (DI/IO_{0}), STM32-MCU.32 (PA7)
/SPI1_SCK: ADC.8 (SCLK), IMU.23 (SCL/SCLK), SD Card.5 (CLK), SPI Flash.6 (CLK), STM32-MCU.30 (PA5)
/SWCLK: STM32-MCU.76 (PA14), SWD.4 (SWCLK)
/SWDIO: STM32-MCU.72 (PA13), SWD.2 (SWDIO)
/SWO: STM32-MCU.89 (PB3), SWD.6 (SWO)
/Temp_ADC: R20.2, STM32-MCU.24 (PA1), TH_NTC.1
GND: ADC.3 (GND), ADC.4 (IN2), Battery.1 (TEMP), Battery.3 (GND), Boost Conv.2 (GND), C1.2, C2.2, C3.2, C4.2, C5.2, C6.2, C7.2, C8.2, C9.2, C10.2, C11.2, C12.2, C13.2, C14.2, C15.2, C16.2, C17.2, C18.2, C19.2, C20.2, C21.2, C22.2, C23.2, C24.2, C25.2, C26.2, C27.2, C28.2, C_Bulk.2, C_Bulk#2.2, C_Bulk#3.2, CurrentSensor.3 (GND), CurrentSensor.7 (A0), CurrentSensor.8 (A1), IMU.11 (FSYNC), IMU.18 (GND), IMU.20 (GND), LDO.1 (GND), LED1.2 (VSS), LED2.2 (VSS), LED3.2 (VSS), LED4.2 (VSS), Mag.6 (GND), Mag.8 (GND), R3.1, R4.1, R5.2, R6.2, R7.2, R8.2, R17.2, R18.2, R19.1, SD Card.6 (VSS), SD Card.9 (SHIELD), SPI Flash.4 (GND), STM32-MCU.10 (VSS), STM32-MCU.19 (VSSA), STM32-MCU.20 (VREF-), STM32-MCU.27 (VSS), STM32-MCU.49 (VSS), STM32-MCU.74 (VSS), STM32-MCU.99 (VSS), SWD.5 (GND), TH_NTC.2, USB-C.A1 (GND), USB-C.A12 (GND), USB-C.B1 (GND), USB-C.B12 (GND), USB-C.S1 (SHIELD), WatchDog.2 (GND), Y1.2 (GND)
unnamed: Battery.5 (BAT), D1.2 (A)
unnamed: C7.1, D2.1 (K), L1.2
unnamed: R4.2, USB-C.A5 (CC1)
unnamed: R3.2, USB-C.B5 (CC2)
unnamed: LED1.3 (DIN), R_Din.2
unnamed: LED2.3 (DIN), LED3.1 (DOUT)
unnamed: LED2.1 (DOUT), R_Din.1
unnamed: LED3.3 (DIN), LED4.1 (DOUT)
unnamed: R1.2, Switch.2
unnamed: R2.2, SPI Flash.3 (~WP/IO_{2})
unnamed: R6.1, Switch.1, WatchDog.3 (DELAY/M_RST)
unnamed: Battery.4 (V_{CC}), Battery.8 (CE), USB-C.A4 (VBUS), USB-C.A9 (VBUS), USB-C.B4 (VBUS), USB-C.B9 (VBUS)
unnamed: Battery.2 (PROG), R5.1
unnamed: Boost Conv.3 (FB), R7.1, R8.1
unnamed: Boost Conv.1 (SW), L1.1
unnamed: C13.1, Mag.5 (C1)
unnamed: Mag.1 (SCL/SPC), R10.2
unnamed: Mag.4 (SDA/SDI/SDO), R9.1
unnamed: C16.1, IMU.10 (REGOUT)
unnamed: FB1.1, STM32-MCU.22 (VDDA)
unnamed: CurrentSensor.2 (IN-), R_Shunt1.1
